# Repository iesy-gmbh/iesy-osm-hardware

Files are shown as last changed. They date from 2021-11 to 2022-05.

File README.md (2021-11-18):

# iesy-osm-hardware
Hardware documentation for iesy OSM-Modules and Eval-Platforms

### OSM Modules:

| Module | OSM Size | Product State | Eval-Platform | Project Name |
| --- | --- | --- | --- | --- |
| iesy RPX30 OSM-SF | Size-S | Testing of REV1.00 | iesy RPX30 EVA-MI | CM006 |
| iesy i.MX8M Mini OSM-SF | Size-S | In Development | iesy i.MX8M EVA-MI |CM007 |

### Eval-Platform:
iesy OSM evaluation concept is based on a modular carrier board that is assembled with currently OSM modules and compatible with modules released in the future.

| Name | Formfactor | Product state | Module | Project Name |
| --- | --- | --- | --- | --- |
| iesy RPX30 EVA-MI | mini-ITX | Testing of REV1.00 | iesy RPX30 OSM-SF |BB138 |
| iesy i.MX8M EVA-MI | mini-ITX | In Development | iesy i.MX8M Mini OSM-SF |BB138 |

### OSM-Specification
See https://sget.org/standards/osm/ for newest release of specification.

### Document files:
The following document files are provided in this repository.

BallOut (*.xlsx)
* List of all module contacts / pins that are provided at OSM interface and specification of voltages, pin-directions and important customer notes for carrier implementation

Muxing-Files (*.mex)
* Configuration of SOC pin muxing based on NXP Config Tool; only available for i.MX8M Mini OSM-SF

Schematic-File (*.pdf)
* Entire Schematic print of the embedded design.

Assembly-File (*.pdf)
* Assembly Printing for all components of the embedded design.

### License:
Except where otherwise noted, licensed under a [Creative Commons Plus (CC+) Dual License](https://wiki.creativecommons.org/wiki/CCPlus).

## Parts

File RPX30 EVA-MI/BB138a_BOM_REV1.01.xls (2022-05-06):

Bill of Materials
Project: | BB138.PrjPcb
Variant: | BB138a
Revision: | 1.01
LK: | 02.0500.0763
Art-Nr. | 20.0003.9936
Creation Date: | 06.05.2022 |  | 10:39
Bearbeiter: | MAS
Art-Nr | Quantity | Designator | Value | Description | Hersteller | Bestellbezeichnung | Footprint | S/T | Hersteller1 | Bestellbezeichnung1 | Lieferant
03.0100.0325 | 1 | XB14 | EPJ35-2509FP-05W-L | Klinke; Buchse; Audio; 3,5mm; THT ; grün | Amtek | EPJ35-2509FP-05W-L | EPJ_gruen | THT |  |  | Amec
03.0100.0328 | 1 | XB10 | USBA_3.0_RA_V | 9pol. Buchse, USB3.0, RA-V, Type A | Molex | 484040003 | USB-A-30_SIDE-90_Molex | THT
03.0100.0366 | 1 | XB22 | RJ45-RA | 14pol. Buchse, RJ45 Transformer, RA, 4 x LED, without wings | Wuerth Elektronik | 74981104400 | RJ45_MU_ML_RO_WE | THT |  |  | Wuerth Elektronik
03.0100.0367 | 1 | XB9 | 482040001 | 4pol. Buchse, USB2.0, RA-V, Type A; Reverse Mount | Molex | 482040001 | 482040001 | THT
03.0100.0368 | 2 | XB24, XB25 | PPTC081LFBN-RC | Buchse; 1x8; THT; pitch=2,54mm | Sullins | PPTC081LFBN-RC | PPTC081LFBN-RC | THT
03.0101.0103 | 1 | XB11 | USB_uB | 5pol. Buchse, USB2.0, RA, Type micro B | Wuerth Elektronik | 629105150521 | USB-MICRO-B | SMT |  |  | Wuerth Elektronik
03.0101.0104 | 1 | XB4 | MicroSD-Card-Sockel_ATTEND_J | Micro SD-Card Sockel; SMD; Push-Push; Top Mount | ATTEND | 112J-TDAR-R01 | Micro-SD-Card-Connector-ATTEND_J | SMD
03.0101.0126 | 2 | XB3, XB26 | SFW15S-2STE1LF | Buchse; 1x15; SMD; pitch=1mm; Serie: FPC-FFC; ZIF | Amphenol | SFW15S-2STE1LF | SFW15S-2STME1LF | SMD
03.0101.0127 | 1 | XB8 | USB_uAB | 5pol. Buchse, USB2.0, RA, Type micro AB | Wuerth Elektronik | 629105150921 | USB-MICRO-AB | SMD
03.0104.0001 | 1 | XS4 | U.FL-R-SMT-1 | 1pol. Buchse, U.FL Serie | Hirose | U.FL-R-SMT-1 | BU_U.FL-R-SMT-1 | SMD
03.0300.0153 | 1 | XS2 | A-SL200-D-G-G-44-D | Stiftleiste; 2x22; THT; pitch=2mm | Assmann | A-SL200-D-G-G-44-D | ST2X22-2.0 | THT
03.0300.0316 | 2 | XS6, XS7 | NRPN061PAEN-RC | Stiftleiste; 1x6; THT; pitch=2mm | Sullins | NRPN061PAEN-RC | ST1x6 | THT
03.0400.0229 | 1 | XS3 | PJ-082BH | Stecker; 1pol.; abgewinkelt; Typ: DC Power Jack | CUI INC | PJ-082BH | PJ-082BH | THT | JAOYU | DC-528 | pk components/Amec
03.0600.0082 | 1 | XB17 | 973582101 | Messsteckverbinder; THT; 4mm; abgewinkelt; Rot | Hirschmann | 973582101 | 973582101 | THT
03.0600.0083 | 1 | XB18 | 973582100 | Messsteckverbinder; THT; 4mm; abgewinkelt; Schwarz | Hirschmann | 973582100 | 973582100 | THT
03.0700.0051 | 1 | XS5 | 61202021621 | Wanne-Stiftleiste; 2x10; THT; pitch=2,54mm | Wuerth Elektronik | 61202021621 | 61202021621 | THT | Assmann | AWHW 20G-0202
04.0501.0053 | 1 | IC4 | SN74LVC1G06 | SINGLE, LVCMOS Inverter, Open-Drain | TI | SN74LVC1G06DBV | SOT23-5 | SMD
04.0501.0054 | 10 | IC15, IC21, IC22, IC27, IC38, IC39, IC40, IC41, IC42, IC43 | SN74LVC1G07DBV | SINGLE, LVCMOS Buffer, Open-Drain | TI | SN74LVC1G07DBV | SOT23-5 | SMD
04.0501.0070 | 2 | IC5, IC24 | SN74AXC4T774PWR | Level Shifter, 3-state, 4 Bit input, independent direction | TI | SN74AXC4T774PWR | TSSOP16_TI | SMD
04.0601.0135 | 3 | IC1, IC19, IC37 | TXS0102DCU | 2-Bit Bidirectional Voltage-Level Translator; +/- 15kV ESD; Open-Drain Output and Push-Pull | TI | TXS0102DCU | VSSOP8 | SMD | Nexperia | NXS0102DCH
04.0601.0162 | 1 | IC12 | FT232RQ | USB to SINGLE UART/FIFO Controller | FTDI | FT232RQ | QFN32_5X5+EP1 | SMD
04.0601.0182 | 1 | IC14 | VSC8541XMV-02 | 10/100/1000Base-T; Gigabit Ethernet Phy; Supports GMII, RGMII, MII, RMII | Microchip | VSC8541XMV-02 | QFN68+EP-2 | SMD
04.0601.0183 | 1 | IC16 | TLV320AIC3253IRGET | Ultra Low Power Stereo Audio Codec With Embedded miniDSP | TI | TLV320AIC3253IRGET | VQFN24_4x4mm_H=1mm | SMD
04.0701.0041 | 1 | IC29 | LM75 | Temperatursensor; Digital; I2C-Interface | TI | LM75BIM-3/NOPB | SOP8 | SMD | Maxim | LM75BIMX-3+
04.0701.0102 | 1 | IC30 | AT24C64D | 64Kbit (Word Size x8bit) Serial EEPROM; 2-Wire | ATMEL | AT24C64D-SSHM | SO8 | SMD | ON | CAT24C64WI-GT3 | Arrow
04.0701.0215 | 2 | IC17, IC18 | ICS‐41350 | Microphone; Digital; PDM-Interface | InvenSense | ICS‐41350 | LGA_CAV | SMD
04.0701.0221 | 3 | IC6, IC7, IC8 | AP22615A | SINGLE Power Distribution Switch; Adjustable Current-Limited | Diodes | AP22615AWU-7 | TSOT-26 | SMD
04.0901.0070 | 1 | SR2 | LTC3869EUFD | Dual, 2-Phase Synchronous Step-Down DC/DC Controllers | Analog Devices | LTC3869EUFD#PBF | QFN28_4x5+EP1 | SMD
04.0901.0118 | 1 | SR8 | MIC5366-1.8 | High-Performance Single LDO | Micrel | MIC5366-1.8YC5-TR | SC70-5L | SMD
04.0901.0140 | 4 | SR1, SR7, SR9, SR10 | ADP1741ACPZ-R7 | Low-Drouput Linear Regulator, Adjustable | Analog Devices | ADP1741ACPZ-R7 | QFN16_4x4+EP | SMD
04.0901.0141 | 3 | SR3, SR4, SR5 | LT8636 | Synchronous Step-Down Silent Switcher with Quiescent Current | Analog Devices | LT8636HV#PBF | QFN20_3x4+EP1+4MP | SMD
05.0101.0005 | 2 | D3, D6 | MBRM140T | MBRM140T | onsemi | MBRM140T1G | PP-D | SMD | onsemi | NRVBM140T1G
05.0101.0016 | 2 | D4, D5 | MBR0540 | MBR0540 | ON Semiconductor | MBR0540T1G | SOD123 | SMD
05.0101.0023 | 1 | ZD10 | SM15T33CA | TVS 7,75x5,55mm; 33V; 8kV; bidirectional | ST Microelectronics | SM15T33CA | SMC_BI_ST | SMD | Diodes | SMCJ28CA-13-F
05.0201.0014 | 1 | ZD9 | 10V | Zener 3,7x1,6mm; 10V; 500mW | NXP | BZV55-C10,115 | MINIMELF_D | SMD
05.0201.0032 | 4 | ZD2, ZD4, ZD6, ZD19 | SMAJ5.0A | TVS 4,60x2,92mm; 6,7V; 400W; 30kV | Littelfuse | SMAJ5.0A | SMA_LITTLEFUSE | SMD | ST
05.0401.0018 | 6 | LD9, LD19, LD21, LD22, LD23, LD24 | LED YE | LED Yellow; 0603; 2V; If max=30mA; 590nm | Würth Elektronik | 150060YS75000 | LED1608-0603 | SMD
05.0401.0020 | 10 | LD4, LD8, LD10, LD11, LD12, LD13, LD14, LD15, LD16, LD18 | LED GN | LED Green; 0603; 3,2V; If max=30mA; 520nm | Würth Elektronik | 150060GS75000 | LED1608-0603 | SMD
05.0401.0044 | 1 | LD3 | LED RD GN | LED Red/Green; 1,6x1,25mm; 2,5V[RD]; 2,5V[GN]; If max=30mA[RD]; If max=30mA[GN]; 630nm[RD]; 570nm[GN] | Kingbright | KPTB-1612SURKCGKC | KPTB-1612 | SMD
05.0701.0007 | 6 | ZD1, ZD14, ZD15, ZD18, ZD22, ZD24 | 82356050101 | ESD TVS 0603; 5V; 15kV; bidirectional | Wuerth | 82356050101 | CD1608_0603_WUERTH | SMD
05.0701.0009 | 1 | ZD7 | TPD4EUSB30 | ESD Array TVS 2,5x1mm; 7V; 8kV; 4-Kanal; USB3.0 | Texas Instruments | TPD4EUSB30DQAR | USON-10_TI | SMD
05.0701.0010 | 2 | DA5, DA6 | RClamp0524P | ESD Array TVS 1,5x0,9mm; 8V; 12kV; DDI Interfaces | Semtech | RClamp0524P | SLP2510P8_SEM | SMD | Semtech | RCLAMP0524PATCT
05.0701.0011 | 4 | ZD3, ZD5, ZD8, ZD11 | TPD2EUSB30 | ESD Array TVS 1,05x0,85mm; 7V; 8kV; 2-Kanal; USB3.0 | Texas Instruments | TPD2EUSB30DRTR | DRT-PDSO-N3_TI | SMD | Texas Instruments | TPD2E009DRTR
06.0001.0073 | 1 | T3 | NVD5117PLT4G | P-Channel MOSFET Vds=-60V, Id=-50A, Rdson=16mOhm | ON Semiconductor | NVD5117PLT4G | DPAK | SMD | Vishay | SUD50P06-15-GE3
06.0001.0111 | 1 | T9 | SI3443DDV | P-Channel MOSFET Vds=-20V, Id=-4A, Rdson=90mOhm | Vishay | SI3443DDV-T1-GE3 | TSOP-6 | SMD
06.0001.0115 | 2 | T7, T8 | IPG20N10S4-36A | N-Channel DUAL MOSFET Vds=100V, Id=20A, Rdson=36mOhm | Infineon | IPG20N10S436AATMA1 | PG-TDSON-8 | SMD
08.0001.0038 | 2 | C20, C96 | 10nF | Ceramic 0603; 50V; X7R; 10% |  |  | CC1608-0603 | SMD
08.0001.0041 | 5 | C135, C178, C276, C343, C349 | 1nF | Ceramic 0603; 50V; C0G |  |  | CC1608-0603 | SMD
08.0001.0083 | 2 | C138, C139 | 47uF | Ceramic 1210; 6,3V; X5R |  |  | CC3225-1210 | SMD
08.0001.0111 | 3 | C237, C248, C259 | 4,7pF | Ceramic 0603; 50V; C0G |  |  | CC1608-0603 | SMD
08.0001.0115 | 2 | C203, C218 | 680pF | Ceramic 0603; 50V; C0G; 10% |  |  | CC1608-0603 | SMD
08.0001.0136 | 15 | C46, C66, C69, C72, C108, C117, C204, C217, C234, C235, C245, C246, C256, C257, C337 | 1uF | Ceramic 0603; 50V; X6S |  |  | CC1608-0603 | SMD
08.0001.0152 | 22 | C70, C109, C116, C118, C122, C129, C130, C134, C142, C145, C146, C148, C208, C214, C222, C269, C270, C292, C335, C336, C367, C368 | 10uF | Ceramic 0603; 10V;X5R |  |  | CC1608-0603 | SMD
08.0001.0160 | 11 | C199, C200, C233, C239, C240, C244, C250, C251, C255, C261, C262 | 10uF | Ceramic 1206; 50V; X7R |  |  | CC3216-1206 | SMD
08.0002.0009 | 7 | C212, C226, C228, C229, C230, C299, C300 | 1000pF | Ceramic 0402; 50V; X7R |  |  | CC1005-0402 | SMD
08.0002.0013 | 2 | C215, C227 | 10pF | Ceramic 0402; 50V; C0G; 5% |  |  | CC1005-0402 | SMD
08.0002.0018 | 100 | C1, C54, C55, C59, C65, C71, C94, C95, C97, C99, C100, C101, C107, C110, C111, C112, C113, C114, C115, C119, C120, C121, C125, C126, C127, C128, C133, C140, C141, C143, C144, C147, C151, C153, C154, C156, C157, C158, C172, C173, C174, C196, C197, C198, C205, C206, C220, C236, C247, C258, C280, C281, C283, C284, C285, C286, C289, C291, C293, C294, C295, C296, C297, C298, C303, C304, C305, C306, C313, C314, C315, C316, C317, C318, C319, C320, C321, C322, C323, C324, C325, C326, C327, C328, C329, C330, C331, C332, C357, C358, C362, C365, C369, C405, C406, C412, C413, C414, C415, C416 | 0,1uF | Ceramic 0402; 50V; X7R |  |  | CC1005-0402 | SMD
08.0002.0020 | 3 | C216, C219, C231 | 100pF | Ceramic 0402; 50V; C0G |  |  | CC1005-0402 | SMD
08.0002.0021 | 2 | C106, C359 | 27pF | Ceramic 0402; 50V; C0G |  |  | CC1005-0402 | SMD
08.0002.0022 | 24 | C61, C67, C73, C98, C124, C132, C192, C209, C213, C223, C241, C252, C263, C268, C274, C279, C339, C342, C345, C348, C356, C361, C364, C407 | 1uF | Ceramic 0402; 25V; X5R |  |  | CC1005-0402 | SMD
08.0002.0023 | 16 | C41, C64, C93, C123, C131, C149, C150, C152, C155, C266, C273, C338, C341, C344, C347, C366 | 4,7uF | Ceramic 0402; 10V; X5R |  |  | CC1005-0402 | SMD
08.0002.0028 | 3 | C242, C253, C264 | 2200pF | Ceramic 0402; 50V; X7R |  |  | CC1005-0402 | SMD
08.0201.0012 | 3 | C56, C62, C68 | 220uF | Tantal Shape E; 16V; gepolt | KEMET | B45197A3227K509 | KEMET_SHAPE_E | SMD | AVX | TPSE227K016R0100
08.0201.0051 | 2 | C207, C221 | 150uF | Polymer Shape B2; 6,3V; ESR 35mOhm; 105°C | Panasonic | 6TPE150MAZB | Panasonic_POSCAP_B2 | SMD
08.0401.0030 | 2 | C210, C224 | 330uF | Polymer Shape D2; 6,3V; ESR 40mOhm; 105°C | Panasonic | 6TPC330MA | Panasonic_POSCAP_D2 | SMD
08.0401.0031 | 5 | C201, C202, C232, C243, C254 | 15uF | Polymer Shape D2; 35V; ESR 150mOhm; 105°C | Panasonic | 35TQC15MYF | Panasonic_POSCAP_D2 | SMD
08.0401.0052 | 7 | C25, C238, C249, C260, C282, C308, C360 | 47uF | Tantal Shape D; 25V; ESR 65mOhm | KEMET | T521D476M025ATE065 | KEMET_SHAPE_D | SMD
08.0401.0066 | 1 | C190 | 100uF | ALU DxL 8,0x10,5; 50V; gepolt | Panasonic | EEE1HA101UP | Panasonic_OS-CON_F | SMD
09.0001.0042 | 2 | R285, R420 | 2,2kOhm | Resistor 0603; 1/16W; 1% |  |  | CR1608-0603 | SMD
09.0001.0121 | 1 | R189 | 0,01Ohm | Resistor 2512; 1W; 1% |  |  | CR6332-2512_KELVIN | SMD
09.0001.0199 | 2 | R218, R291 | 3,6kOhm | Resistor 0603; 1/16W; 1% |  |  | CR1608-0603 | SMD
09.0001.0200 | 1 | R294 | 2,49kOhm | Resistor 0603; 1/10W; 1% |  |  | CR1608-0603 | SMD
09.0001.0202 | 6 | R198, R199, R203, R204, R208, R209 | 2MOhm | Resistor 0603; 1/10W; 1% |  |  | CR1608-0603 | SMD
09.0001.0203 | 1 | R197 | 34kOhm | Resistor 0603; 1/16W; 1% |  |  | CR1608-0603 | SMD
09.0001.0231 | 1 | R283 | 7,5kOhm | Resistor 0603; 1/16W; 1% |  |  | CR1608-0603 | SMD
09.0001.0243 | 1 | R174 | 0,018Ohm | Resistor 2512; 1W; 1% | NIC |  | CR6332-2512_KELVIN | SMD
09.0001.0261 | 2 | R193, R194 | 180kOhm | Resistor 0603; 1/10W; 1% |  |  | CR1608-0603 | SMD
09.0001.0272 | 2 | R57, R62 | 12kOhm | Resistor 0603; 1/10W; 1% |  |  | CR1608-0603 | SMD
09.0001.0273 | 1 | R173 | 2,2Ohm | Resistor 0603; 1/16W; 1% |  |  | CR1608-0603 | SMD
09.0001.0317 | 1 | R172 | 5,1Ohm | Resistor 1206; 1/4W; 1% |  |  | CR3216-1206 | SMD
09.0001.0318 | 1 | R182 | 5,62Ohm | Resistor 1206; 1/4W; 1% |  |  | CR3216-1206 | SMD
09.0001.0349 | 2 | R201, R202 | 43,2kOhm | Resistor 0603; 1/20W; 1% |  |  | CR1608-0603 | SMD
09.0002.0002 | 27 | R1, R2, R53, R54, R59, R64, R89, R90, R93, R111, R116, R136, R137, R138, R215, R219, R225, R226, R227, R228, R229, R233, R254, R255, R261, R262, R299 | 0Ohm | Resistor 0402; 1/16W |  |  | CR1005-0402, CR1005-0402-HD | SMD
09.0002.0003 | 6 | R129, R186, R187, R214, R289, R292 | 100kOhm | Resistor 0402; 1/16W; 1% |  |  | CR1005-0402 | SMD
09.0002.0004 | 46 | R5, R6, R7, R8, R9, R50, R55, R58, R60, R61, R82, R83, R84, R85, R86, R131, R133, R141, R142, R170, R180, R183, R184, R188, R190, R195, R196, R216, R236, R244, R245, R248, R249, R250, R251, R259, R260, R263, R276, R277, R278, R279, R290, R293, R387, R388 | 10kOhm | Resistor 0402; 1/16W; 1% |  |  | CR1005-0402 | SMD
09.0002.0005 | 1 | R130 | 2,2kOhm | Resistor 0402; 1/16W; 1% |  |  | CR1005-0402 | SMD
09.0002.0011 | 4 | R200, R205, R210, R280 | 26,7kOhm | Resistor 0402; 1/16W; 1% |  |  | CR1005-0402 | SMD
09.0002.0013 | 4 | R163, R321, R426, R428 | 100Ohm | Resistor 0402; 1/16W; 1% |  |  | CR1005-0402 | SMD
09.0002.0014 | 12 | R104, R106, R109, R110, R112, R113, R118, R221, R222, R301, R302, R303 | 33Ohm | Resistor 0402; 1/16W; 1% |  |  | CR1005-0402 | SMD
09.0002.0015 | 1 | R103 | 1MOhm | Resistor 0402; 1/16W; 1% |  |  | CR1005-0402 | SMD
09.0002.0030 | 4 | R375, R376, R377, R378 | 165Ohm | Resistor 0402; 1/16W; 1% |  |  | CR1005-0402 | SMD
09.0002.0031 | 7 | R20, R41, R121, R122, R140, R234, R235 | 1kOhm | Resistor 0402; 1/16W; 1% |  |  | CR1005-0402 | SMD
09.0002.0035 | 3 | R185, R206, R207 | 120kOhm | Resistor 0402; 1/16W; 1% |  |  | CR1005-0402 | SMD
09.0002.0045 | 13 | R123, R124, R282, R284, R286, R287, R288, R311, R314, R315, R316, R318, R319 | 4,7kOhm | Resistor 0402; 1/16W; 1% |  |  | CR1005-0402 | SMD
09.0002.0046 | 2 | R211, R212 | 200kOhm | Resistor 0402; 1/16W; 1% |  |  | CR1005-0402 | SMD
09.0002.0096 | 41 | R176, R177, R191, R192, R224, R274, R275, R295, R320, R390, R391, R392, R393, R394, R395, R396, R397, R398, R399, R400, R401, R402, R403, R404, R405, R406, R407, R408, R409, R410, R411, R412, R413, R414, R415, R416, R417, R418, R419, R423, R424 | 10Ohm | Resistor 0402; 1/16W; 1% |  |  | CR1005-0402 | SMD
09.0002.0117 | 2 | R178, R179 | 300kOhm | Resistor 0402; 1/10W; 1% | Panasonic | ERJ-2RKF3003X | CR1005-0402 | SMD
09.0002.0119 | 1 | R67 | 6,8kOhm | Resistor 0402; 1/16W; 1% |  |  | CR1005-0402 | SMD
09.0002.0143 | 5 | R421, R425, R427, R429, R430 | 560Ohm | Resistor 0402; 1/16W; 1% |  |  | CR1005-0402 | SMD
09.0002.0154 | 4 | R21, R105, R119, R120 | 2kOhm | Resistor 0402; 1/16W; 1% |  |  | CR1005-0402 | SMD
10.0101.0008 | 2 | SH1, SH2 | CHS-01TA | Schalter 5,6x2,5mm; DIP Switch; 1-fach | Copal Electronics Inc. | CHS-01TA | SW1-CHS | SMD | Copal Electronics Inc. | CHS-01TA1
10.0101.0013 | 5 | TA1, TA2, TA3, TA4, TA5 | SKRPACE010 | Taster 4,6x3,2x2,5mm; Compact High Operating Force | ALPS | SKRPACE010 | TA-ALPS-SKRPACE010 | SMD
11.0101.0005 | 1 | SI1 | 7A | Sicherung 9,73x5,03x3,81mm; Sicherung mit Fassung OMNI BLOK Sicherung; 154 Serie; Träge; 7A | Littelfuse | 0154007.DRT | SMF Omni-Blok | SMD
12.0501.0027 | 1 | L29 | 2,2uH | Inductor 7,05x6,6mm; 2,2uH; I_rms=9A; 11,4mOhm; Shielded Power Inductor | Wuerth Elektronik | 744311220 | WE-HC | SMD
12.0501.0041 | 4 | L15, L16, L17, L20 | 120Ohm | Ferrit 0603; I_rms=2A; 50mOhm; Chip Bead | Murata | BLM18PG121SN1 | CR1608-0603 | SMD
12.0501.0128 | 3 | L3, L6, L9 | 600Ohm | Ferrit 0805; I_rms=2A; 150mOhm; EMI-Suppression Bead | Wuerth Elektronik | 742792040 | CR2012-0805 | SMD |  |  | iesy
12.0501.0137 | 3 | L30, L31, L32 | 2,2uH | Inductor 4020; 2,2uH; I_rms=4,7A; 29mOhm; Shielded Power Inductor | Wuerth Elektronik | 74438356022 | WE-MAPI_4020 | SMD |  |  | Wuerth Elektronik
12.0501.0150 | 1 | L28 | 6,8uH | Inductor 4030; 6,8uH; I_rms=3A; 69,4mOhm; Shielded Power Inductor | Wuerth Elektronik | 74438357068 | WE-MAPI_4030 | SMD |  |  | Wuerth Elektronik
12.0501.0194 | 4 | L5, L8, L11, L14 | 90Ohm | Inductor 1210; I_rms=100mA; 90 Ohm; Common mode filters | TDK | MCZ1210DH900L2TA0G | MCZ 1210 | SMD | TDK | MCZ1210AH900L2TA0G
12.0501.0196 | 2 | L12, L13 | 50Ohm | Inductor 1210; I_rms=100mA; 50 Ohm; Common mode filters | TDK | MCZ1210DH500L2TA0G | MCZ 1210 | SMD | TDK | MCZ1210DH500CPTA0G
12.0601.0028 | 1 | Q3 | 25MHz | Quarz 3,2x2,5mm; 16pF; 50ppm | Comtec Crystal | A025000000CIFBPN43DB | QUARZ CM3225 | SMD |  | CM3225- 25MHz | Comtec Crystal

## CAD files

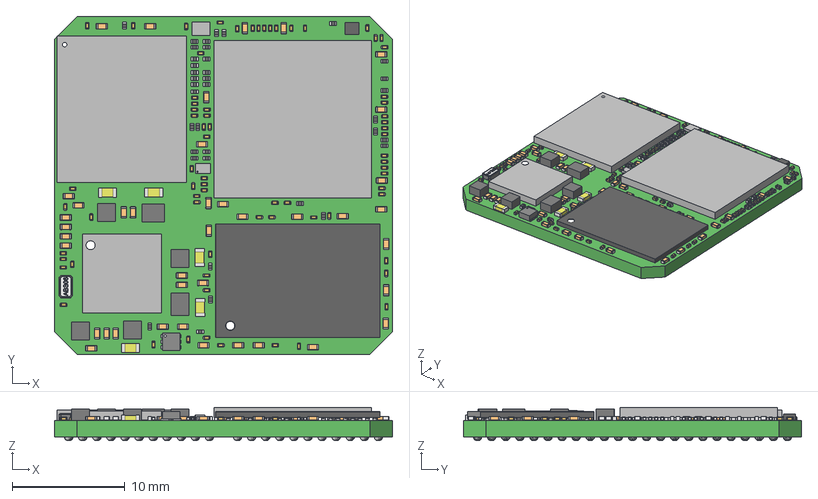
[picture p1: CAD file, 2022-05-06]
i.MX8M Mini OSM-SF/STEP/CM007a_STEP_REV1.01.step
30.0 x 30.0 x 2.95 mm
Open_CASCADE_STEP_translator_6.8_2.1.1 x 71
Open_CASCADE_STEP_translator_6.8_2.1.2 x 71
Open_CASCADE_STEP_translator_6.8_2.2.1 x 71
Extruded x 117
body_SSMC_161610-XXX-SA x 4
land_pattern_SSMC_161610-XXX-SA x 8
CC_0603 x 5
C0402_035 x 120
Open_CASCADE_STEP_translator_6.8_11.1
Open_CASCADE_STEP_translator_6.8_11.2.1
Open_CASCADE_STEP_translator_6.8_11.3.1 x 6
User_Library-ABS06_ABS06_Body_2
User_Library-ABS06_ABS06_Body2_2
User_Library-ABS06_ABS06_Beschriftung_2
User_Library-ABS06_ABS06_Pads_2
body_SSMC_201610-XXX-S x 2
land_pattern_SSMC_201610-XXX-S x 4
BallSilberlot x 332

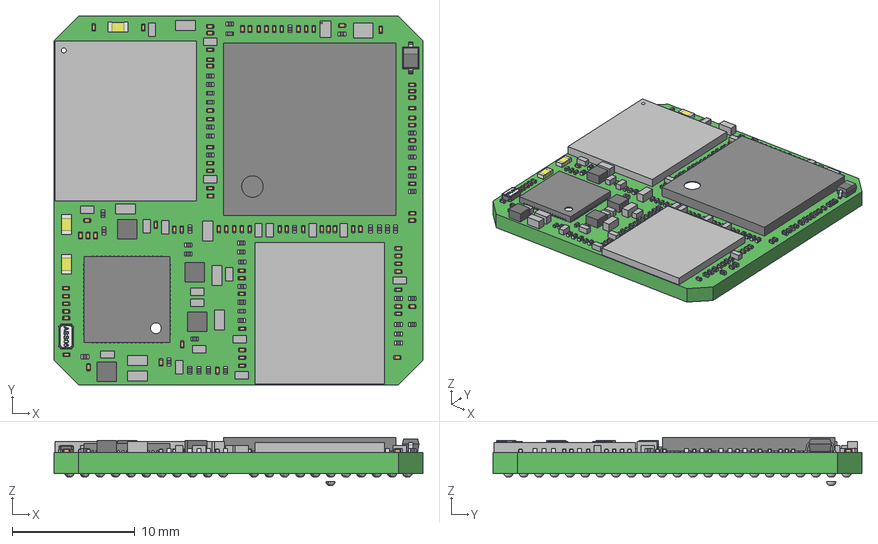
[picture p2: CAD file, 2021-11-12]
RPX30 OSM-SF/STEP/CM006_STEP_REV1.00.step
30.0 x 30.0 x 3.93 mm
Extruded x 156
Mid_Body x 4
Open_CASCADE_STEP_translator_6.8_5.2.1 x 8
Mark x 4
User_Library-ABS06_ABS06_Body_2
User_Library-ABS06_ABS06_Body2_2
User_Library-ABS06_ABS06_Beschriftung_2
User_Library-ABS06_ABS06_Pads_2
Open_CASCADE_STEP_translator_6.8_2.1.1 x 82
Open_CASCADE_STEP_translator_6.8_2.1.2 x 82
Open_CASCADE_STEP_translator_6.8_2.2.1 x 83
CC_0603 x 3
SOD-323
body_SSMC_161610-XXX-SA x 4
land_pattern_SSMC_161610-XXX-SA x 8
Open_CASCADE_STEP_translator_6.8_1.1
Open_CASCADE_STEP_translator_6.8_1.2.1
Thermal_Shape
Open_CASCADE_STEP_translator_6.8_1.4.1 x 68
Open_CASCADE_STEP_translator_6.8_2.1
ball x 441
BallSilberlot x 332

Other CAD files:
i.MX8M Nano OSM-SF/STEP/CM007b_STEP_REV1.01.step

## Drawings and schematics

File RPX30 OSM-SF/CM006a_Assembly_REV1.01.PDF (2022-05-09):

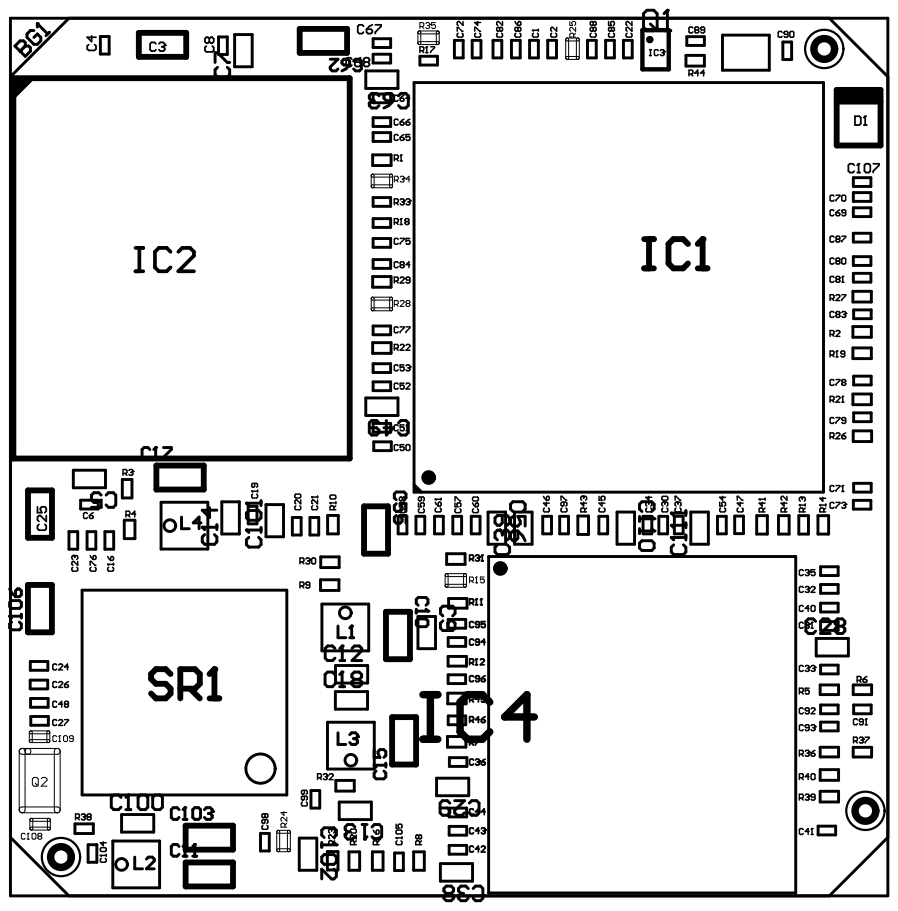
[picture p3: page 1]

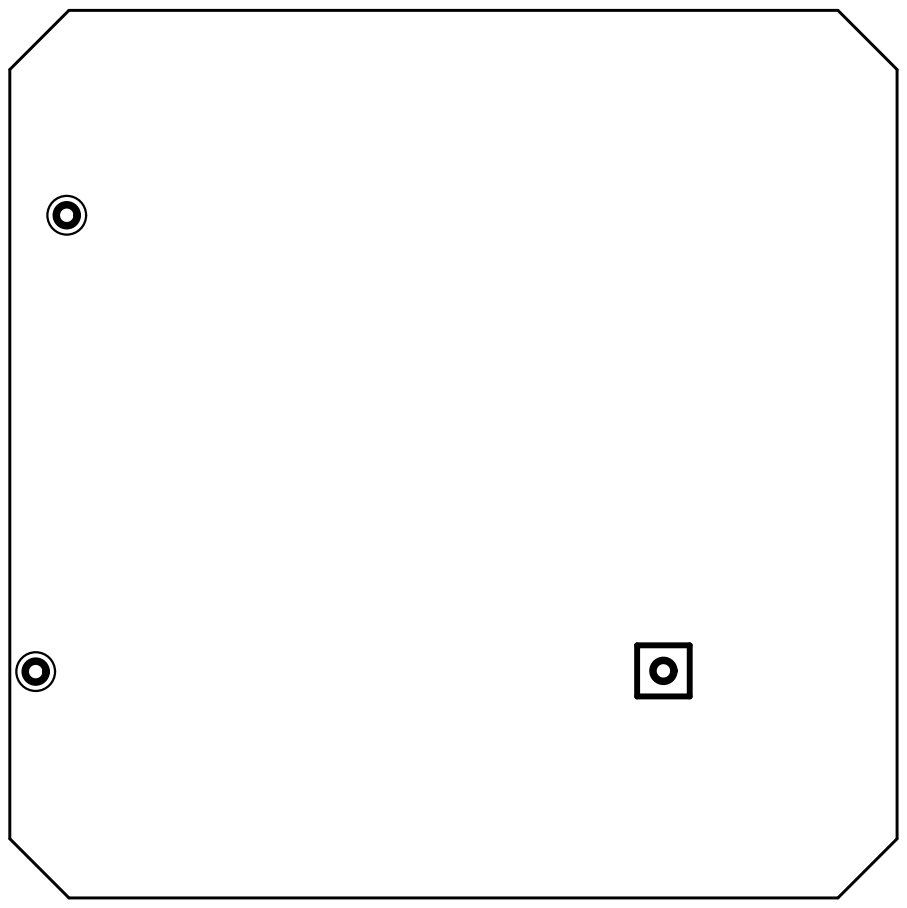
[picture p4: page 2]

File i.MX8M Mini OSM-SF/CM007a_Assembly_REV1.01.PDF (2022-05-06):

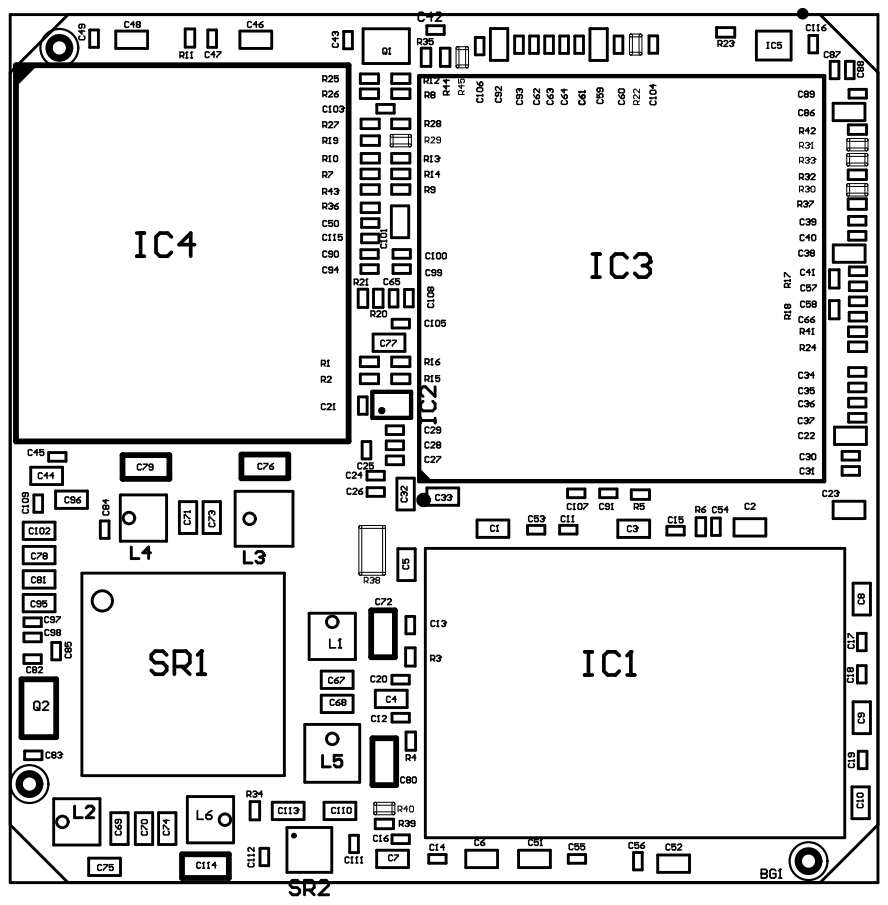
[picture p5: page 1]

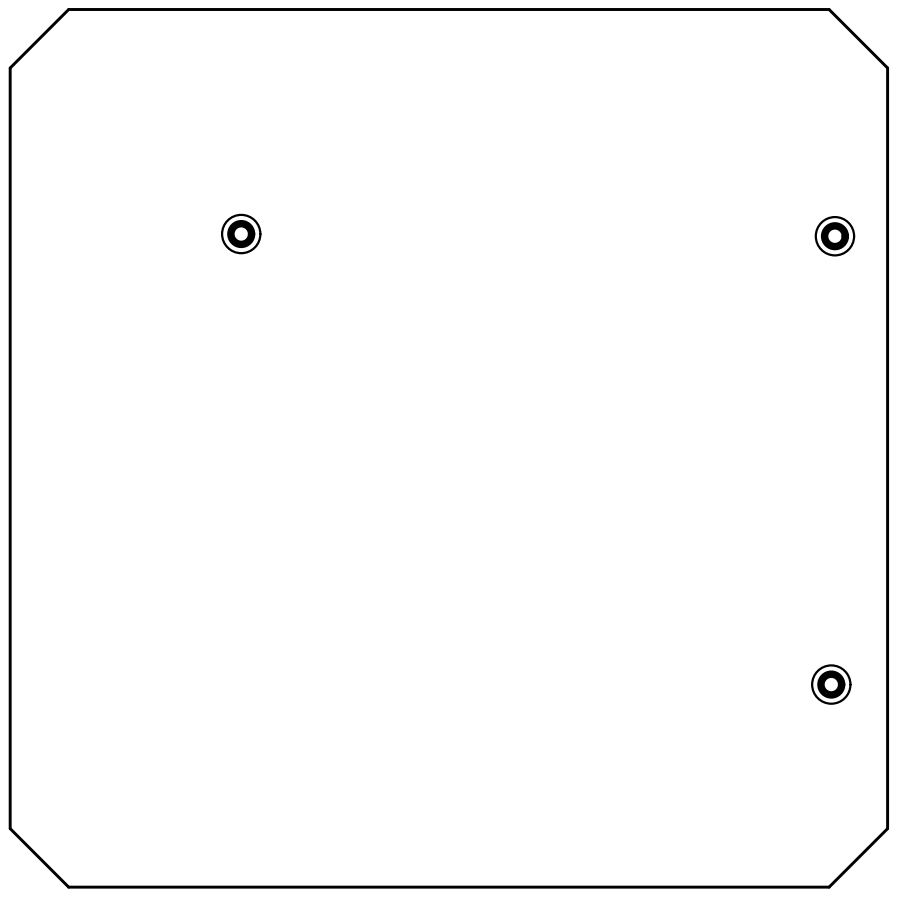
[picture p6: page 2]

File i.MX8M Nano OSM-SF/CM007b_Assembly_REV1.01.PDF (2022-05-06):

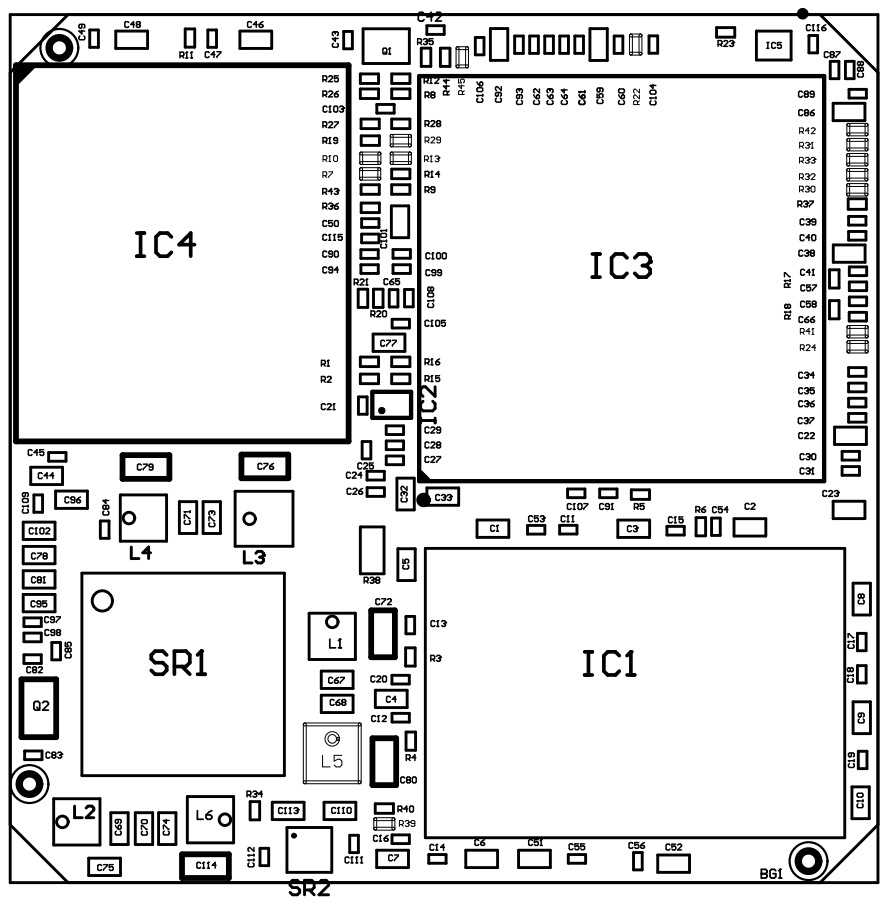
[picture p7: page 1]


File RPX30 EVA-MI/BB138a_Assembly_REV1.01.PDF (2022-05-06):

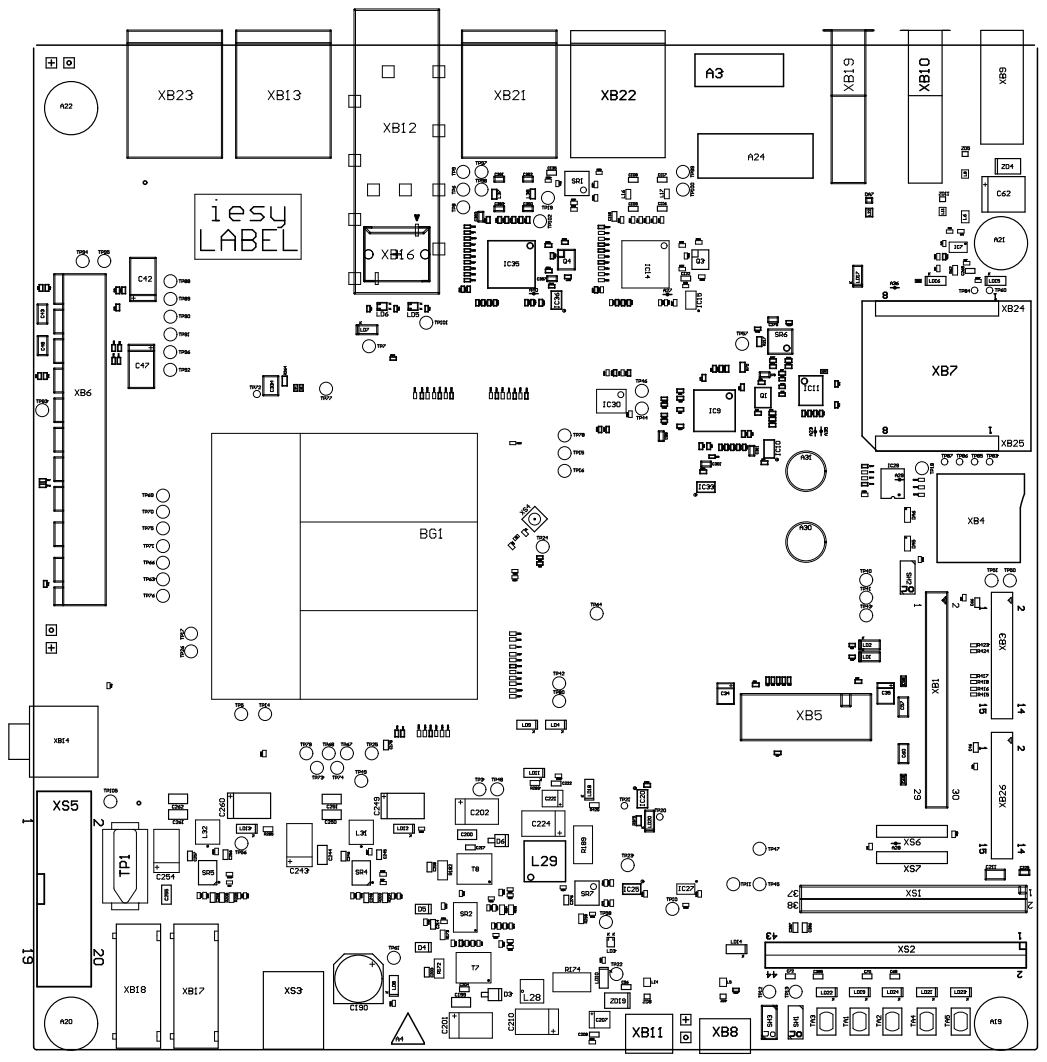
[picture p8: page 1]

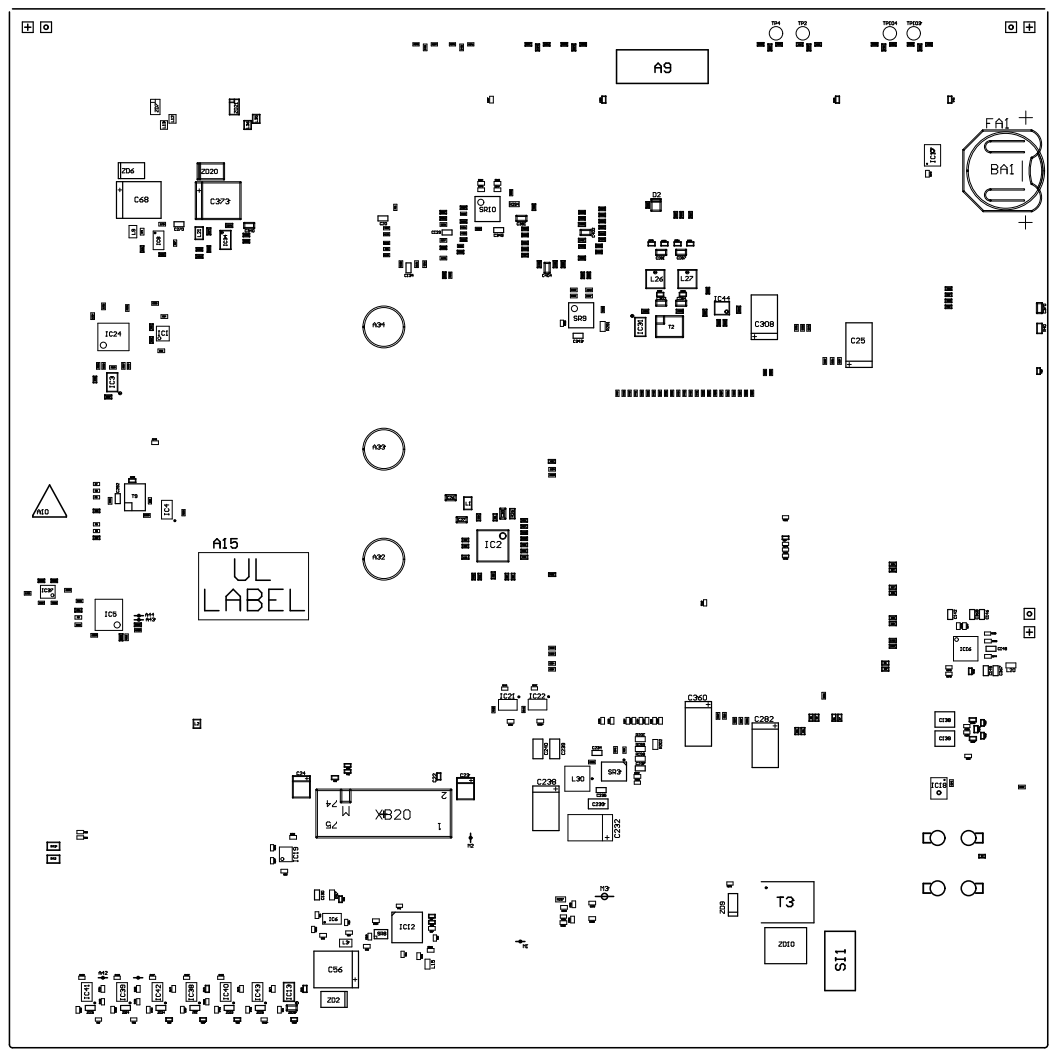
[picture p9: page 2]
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

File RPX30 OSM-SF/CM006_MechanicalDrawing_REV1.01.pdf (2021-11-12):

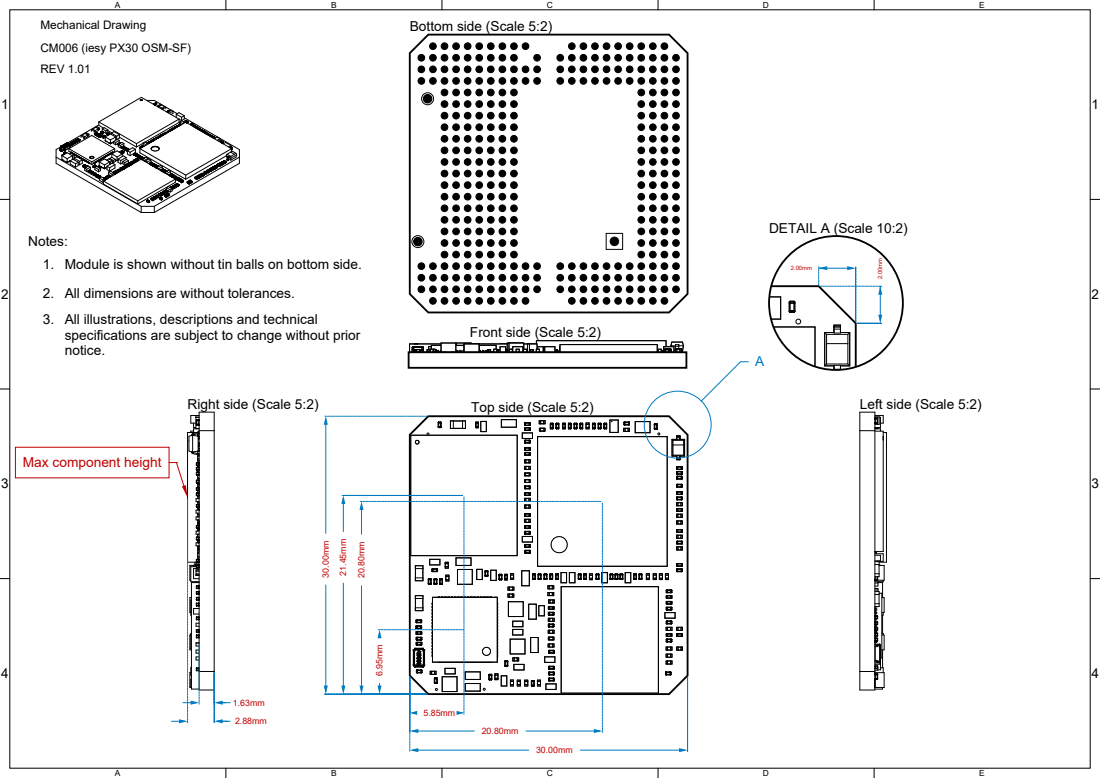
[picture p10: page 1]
Right side (Scale 5:2); Left side (Scale 5:2); DETAIL A (Scale 10:2) 2.00mm

Mechanical Drawing
CM006 (iesy PX30 OSM-SF)
REV 1.01

Bottom side (Scale 5:2)

Notes:
1. Module is shown without tin balls on bottom side.

2. All dimensions are without tolerances.
specifications are subject to change without prior
notice.

All illustrations, descriptions and technical

Front side (Scale 5:2)

Top side (Scale 5:2)

Max component height

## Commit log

2021-07-28 Add pin descriptions of i.MX8M Mini OSM-SF and RPX30 OSM-SF
    [CM006_BallOut_REV0.16.xlsx, CM007_BallOut_REV0.12.xlsx]
2021-11-12 Add schematic for REV1.00
2021-11-12 Add assembly drawing for REV1.00
2021-11-12 Update Ball-List
    [CM006_BallOut_REV0.16.xlsx]
2021-11-12 Add 3D STEP for REV1.00
    [CM006_STEP_REV1.00.step]
2021-11-12 Add bill of materials for REV1.00
    [BB138a_BOM_REV1.00.xls]
2021-11-17 Update Ball-List for REV1.00
    [CM006_BallOut_REV0.16.xlsx, CM006_BallOut_REV1.00.xlsx]
2022-05-06 Update Schematic and Assembly for REV1.01
    [BB138a_BOM_REV1.00.xls, BB138a_BOM_REV1.01.xls]
2022-05-06 Add schematic for i.MX8M Mini/Nano OSM-SF REV1.01
2022-05-06 Add assembly drawing for i.MX8M Mini/Nano OSM-SF REV1.01
2022-05-06 Update Ball-List for i.MX8M Mini/Nano OSM-SF
    [CM007_BallOut_REV0.12.xlsx, CM007_BallOut_REV0.19.xlsx]
2022-05-06 Add 3D STEP for i.MX8M Mini/Nano OSM-SF
    [CM007a_STEP_REV1.01.step, CM007b_STEP_REV1.01.step]
